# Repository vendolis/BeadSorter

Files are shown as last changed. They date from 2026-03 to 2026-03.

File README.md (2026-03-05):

# BeadSorter
The is a modified version based on the bead sorter by HEN3DRIK [BeadSorter](https://github.com/HEN3DRIK/BeadSorter)

# References
These are Projects necessary for this beadsorter to work.

Original Project by Linus Barth:
[BeadSort: Machine for sorting perler beads by LinusB - Thingiverse](https://www.thingiverse.com/thing:2598302)

Modified to skip aligner phase by RichA777
[Bead Sorter modified to skip aligner phase by RichA777 - Thingiverse](https://www.thingiverse.com/thing:4507571)

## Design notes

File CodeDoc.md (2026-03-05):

# BeadSorter

An Arduino-based automated bead sorting machine that uses a color sensor to identify beads and route them into separate containers by color.

---

## Physical Stages

The machine is divided into numbered physical stages, each with corresponding 3D-printed parts:

| Stage | Name | Description |
|---|---|---|
| 0 | Hopper | Bulk bead storage reservoir |
| 1 | Sequentializer | DC motor agitates beads into a single-file tube |
| 3 | Analyzer | Servo-controlled gate presents one bead at a time to the color sensor |
| 4 | Dispatcher | Stepper-driven rotating carousel directs the bead to the correct output |
| 5 | Outputs | Ring of output containers (up to 15 color bins + 1 overflow) |

---

## Hardware

### Components

| Component | Purpose |
|---|---|
| Arduino (Nano/Uno) | Main controller |
| TCS34725 color sensor | Reads RGBC values of each bead via I2C |
| Servo motor | Gate in the analyzer stage — swings in/out to present a bead to the sensor |
| Stepper motor (200 steps/rev) | Rotates the output carousel to the correct container |
| L298N / H-bridge | Drives the DC hopper motor |
| DC motor (hopper) | Agitates beads from the hopper into the sequentializer tube |
| Photoresistor / LDR | Detects whether beads are present in the feeding tube |
| Push button | Setup / calibration trigger |

### Pin Assignments

| Pin | Name | Function |
|-----|---|---|
| D2 | `dirPin` | Stepper direction |
| D3 | `stepPin` | Stepper step pulse |
| D5 | `GSM2` | Hopper motor PWM speed |
| D6 | `in4` | Hopper motor direction B |
| D7 | `in3` | Hopper motor direction A |
| D8 | `servoPin` | Servo PWM |
| D11 | `setupPin` | Setup/calibration button (INPUT) |
| A0 | `photoSensorPin` | Photoresistor (analog) |
| SDA/SCL | I2C | TCS34725 color sensor |

---

## Software Architecture

### Libraries Required

- `Servo.h` — Arduino servo control
- `AccelStepper.h` — Stepper motor with acceleration/deceleration
- `Wire.h` — I2C communication
- `Adafruit_TCS34725.h` — TCS34725 color sensor driver

### Main Loop Flow

```
loop()
  │
  ├─ Handle serial commands (e.g. 't' to print tables)
  │
  ├─ handleHopperMotor()        ← keep beads flowing; reverse if stuck
  │
  ├─ Check setup button         ← if pressed: enter manual color registration
  │
  ├─ servoFeedIn()              ← swing servo to "in" position, presenting bead
  │
  ├─ readColorSensor()          ← read RGBC from TCS34725
  │
  ├─ nullScan()?
  │    ├─ YES (no bead) → print ".", servoFeedOut(), loop
  │    └─ NO  (bead detected)
  │         ├─ sortBeadToDynamicArray()
  │         │    ├─ findColorInStorage()   ← up to 4 retries with wiggle
  │         │    ├─ getContainerNo()       ← map color index → carousel slot
  │         │    └─ moveSorterToPosition() ← rotate stepper to that slot
  │         └─ servoFeedOut()             ← release bead into carousel
```

### Startup Sequence

1. Initialise all pins and peripherals.
2. If `calibrateNullScan = true`: wiggle the servo 6 times (to settle), then read the empty-sensor baseline and store it as the null-scan reference.
3. If `autoSort = false`: load the 13 preset default colors.
4. Begin the main loop.

---

## Operating Modes

### Auto-Sort Mode (`autoSort = true`, default)

The machine learns colors on the fly:
- Every new color that doesn't match anything stored is automatically assigned to the next free container slot.
- Up to **15 distinct colors** can be learned and sorted.
- When all 15 slots are full, unrecognised beads go to the last container (slot 15 = overflow).
- Thresholds: `thresholdFactor = 0.04`, `offset = 40`.

### Manual / Preset Mode (`autoSort = false`)

Activated by pressing the setup button during runtime (or set at compile time):
- Uses 13 hardcoded reference colors (Orange, Yellow, Green, Dark Blue, Rose, Skin, Red, White, Black, Lime Green, Mint Green, Coral, Dark Yellow).
- Tighter matching thresholds: `thresholdFactor = 0.03`, `offset = 20`.
- New colors can still be registered manually — press the setup button, load a single color type into the hopper, then press again to scan 4 samples and compute a mean reference.

---

## Color Matching

### Sensor Configuration

```cpp
Adafruit_TCS34725 tcs = Adafruit_TCS34725(TCS34725_INTEGRATIONTIME_101MS, TCS34725_GAIN_16X);
```

The sensor returns four 16-bit channels: **Clear (C), Red (R), Green (G), Blue (B)**.

### Null Scan (Empty-Sensor Detection)

On startup the empty-sensor RGBC values are recorded as `nullScanValues[]`. Each loop iteration, if the measured RGBC is within ±`nullScanOffset` (150) of these baseline values on all four channels, `nullScan()` returns `true` — meaning no bead is present.

### Color Identification (`findColorInStorage`)

Each stored color is compared channel by channel. For each channel the allowed window is:

```
threshold = thresholdFactor × measured_value + offset
window    = [measured − threshold, measured + threshold]
```

A stored color matches only if **all four channels** fall within their respective windows. The first match found wins.

### Retry Logic

If no match is found immediately, the servo wiggles the bead (`servoWiggleIn`) and re-reads up to **4 times**. The four readings are averaged (mean) before a final unmatched bead is stored as a new auto-color.

### Color Distance (Euclidean)

`colorDistance()` computes the 4D Euclidean distance between two RGBC vectors. This is logged to Serial for debugging but is not used in the primary matching logic (which uses the per-channel threshold approach above).

---

## Stepper / Carousel

| Parameter | Value |
|---|---|
| Steps per revolution | 200 |
| Microstepping | 16× |
| Container slots defined | 16 (12 physically used) |
| Steps per slot | `200 × 16 / 16 = 200` |
| Max speed | 6000 steps/s |
| Acceleration | 9000 steps/s² |

`moveSorterToPosition()` always takes the **shortest path** — if the forward distance is more than 8 slots it wraps around in reverse, and vice versa. After moving, the absolute position is normalised back into the 0–15 slot range to prevent integer overflow over long runs.

### Container Array

`dynamicContainerArray[16]` maps color indices to physical carousel slots. Pre-seeded with sentinel value `666` at slots 1, 5, 9, 13 (reserved/dividers) and `-1` (free) elsewhere. Slot 15 is the overflow bin.

---

## Hopper Motor Control

The DC hopper motor runs continuously while the photosensor reports no beads in the tube (sensor value > `photoSensorThreshold` = 600).

If no bead has been successfully sorted for more than `hopperMotorReverseTime` (9 s), the motor **reverses direction** to dislodge jams. The direction resets on each successful bead.

---

## Servo Positions

| Position | Angle | Description |
|---|---|---|
| In | 28° ± 2° | Bead held under sensor |
| Out | 51° ± 2° | Bead released to carousel |
| Wiggle | ±4° around `In` | Repositions bead for re-reading |

`servoFeedOut()` cycles the "out" wiggle **3 times** to ensure the bead is fully ejected.

---

## Serial Interface

Baud rate: **9600**

| Input | Action |
|---|---|
| `t` or `T` | Print null-scan values, all stored colors, and the container array |

### Output Format

- `.` — no bead detected (null scan)
- `Photosensor detected Beads <value>` — tube is full, hopper stopped
- `Beads analyzed: N` followed by RGBC values — bead detected
- `Color is #<name>` — matched color (manual mode) or RGBC (auto mode)
- `Color Distance is: <d>` — Euclidean distance to matched reference
- `move stepper to container No: <n>` — target slot
- `not found` + `autosort!` — new color being learned

---

## Configuration Reference

All key parameters are `#define` constants at the top of [BeadSorter.ino](BeadSorter.ino):

| Constant | Default | Description |
|---|---|---|
| `stepperMaxSpeed` | 6000 | Stepper max steps/s |
| `stepperAccel` | 9000 | Stepper acceleration steps/s² |
| `stepperStepsPerRot` | 200 | Motor steps per revolution |
| `stepperMicroStepping` | 16 | Driver microstepping factor |
| `numContainerSlots` | 16 | Logical slot count |
| `motorSpeed` | 255 | Hopper motor PWM (0–255) |
| `hopperMotorReverseTime` | 9000 | ms before reversing hopper on jam |
| `photoSensorThreshold` | 600 | ADC level above which tube is empty |
| `nullScanOffset` | 150 | ±tolerance for empty-sensor detection |
| `servoAngleIn` | 28° | Servo scan position |
| `servoAngleOut` | 51° | Servo release position |
| `servoAngleWiggle` | 2° | Servo dither amplitude |
| `thresholdFactor` | 0.04 | Color match window scaling factor |
| `offset` | 40 | Color match minimum window (counts) |
| `calibrateNullScan` | true | Auto-calibrate empty sensor on boot |
| `autoSort` | true | Learn colors automatically |

---

## Debug Modes

Uncomment a `DEBUG_PROG` define to enable a debug loop at startup:

| Value | Mode |
|---|---|
| `1` | Stepper test: repeatedly moves to position 1000 and back |
| `2` | Color sensor test: prints live RGBC readings every 400 ms |

`DEBUG_PRINT_PHOTOSENS` — if defined, prints the raw photosensor ADC value every loop iteration.

---

## Known Issues / Notes

- `calcMedianAndStore()` computes a **mean**, not a median (acknowledged in a comment).
- The `updateDetectedColorFromTempStoredColor` / `updateStoredColorCount` running-average update feature is commented out.

### VS Code IntelliSense warning

IntelliSense may report *"PCH warning: header stop cannot be in a linkage block"* on the last `#include` line. This is **not a real compiler error** — it is caused by `Arduino.h` using `extern "C"` blocks internally which confuse the MSVC-style PCH engine. It is suppressed by setting `"intelliSenseMode": "gcc-x86"` in [.vscode/c_cpp_properties.json](.vscode/c_cpp_properties.json), which matches the actual AVR-GCC toolchain.

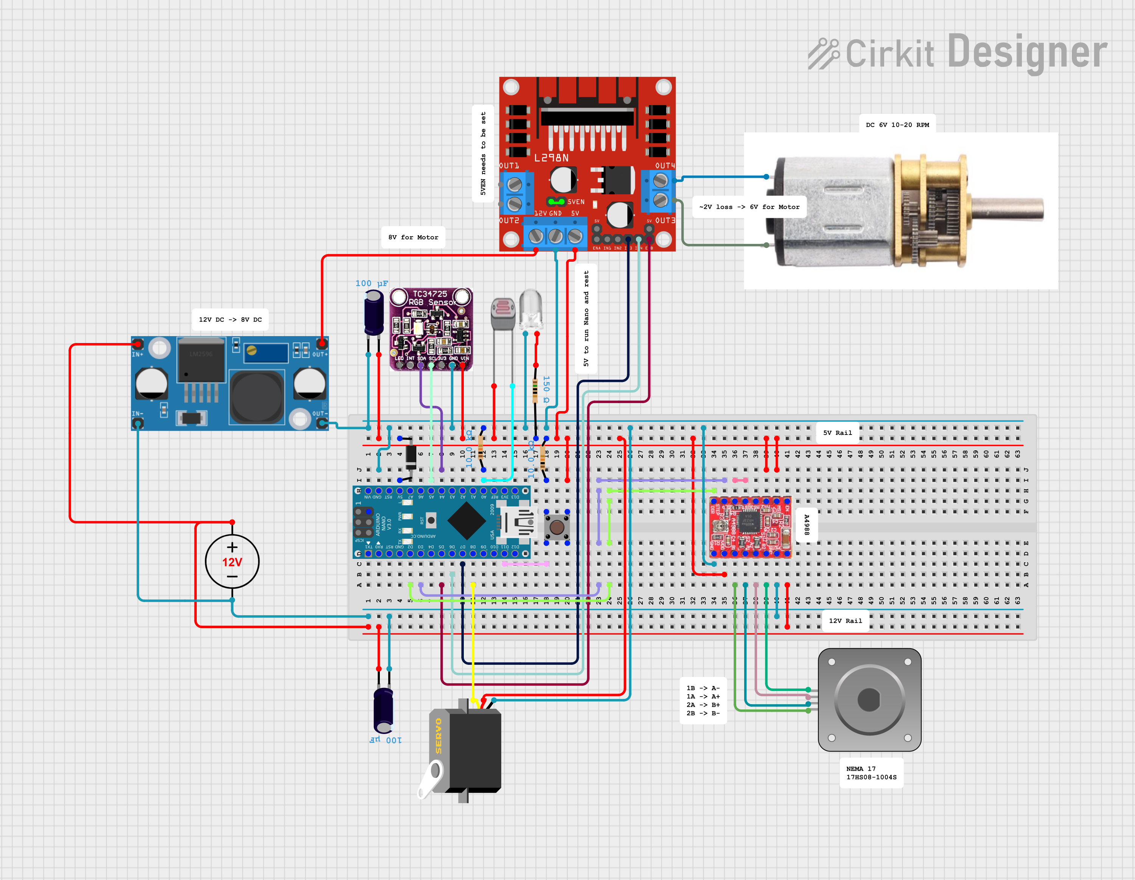
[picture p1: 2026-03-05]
beadsorter_schema_revised_v1.png

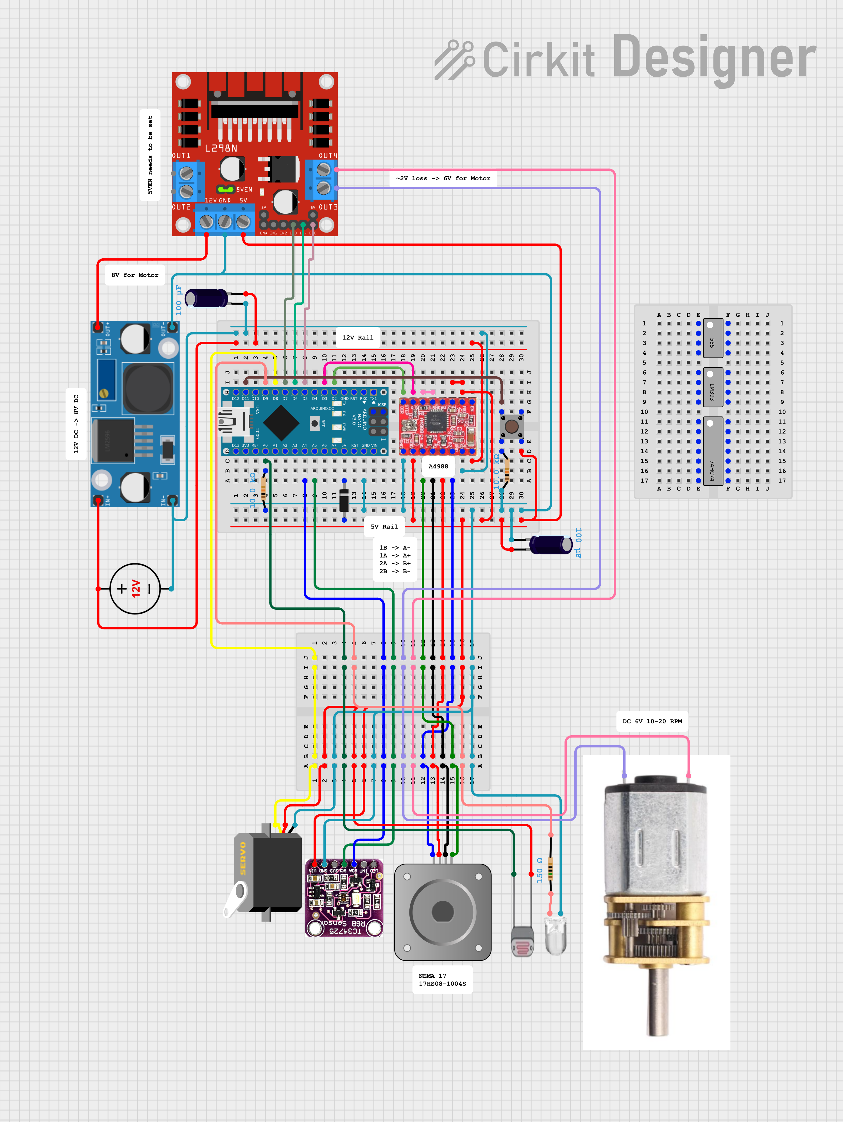
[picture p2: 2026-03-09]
beadsorter_schema_revised_v2.png

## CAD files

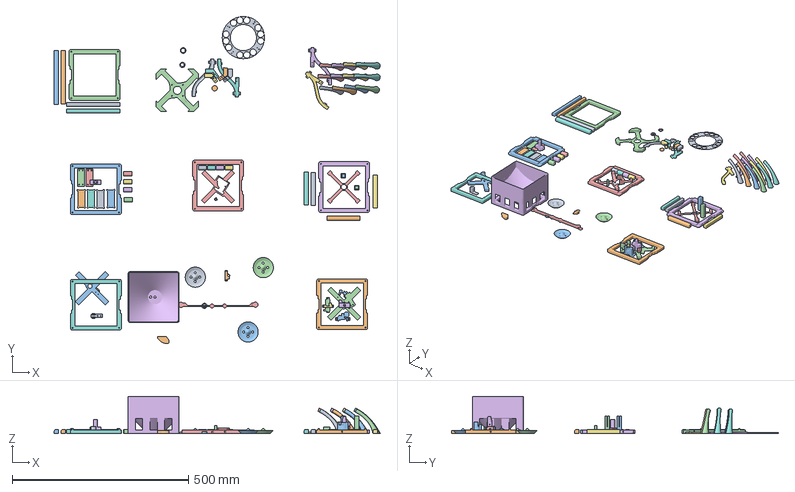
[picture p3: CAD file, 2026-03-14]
Beadsorter.3mf
925.0 x 926.4 x 105.0 mm
0-hopper-seq-plate-4_holes_modified.stl
0-hopper-seq-stopper.stl
1-sequentializer-ilc-bottom.stl
1-sequentializer-ilc-corner_for_higher_motor.stl
1-sequentializer-ilc-top.stl
1-sequentializer-motor-holder.stl
3-analyzer-entry-tube_modified.stl
3-analyzer-exit-base_V7.stl
3-analyzer-exit-tube.stl
3-analyzer-ilc-bottom.stl
3-analyzer-ilc-corner.stl
3-analyzer-ilc-top.stl
3-analyzer-separation-arm_v8.stl
3-analyzer-servo-holder.stl
3-analyzer-top-alignment.stl
4-dispatcher-ilc-bottom.stl
4-dispatcher-ilc-corner.stl
4_Stepper_shaft.stl
4_Stepper_shaft_alternative_3mm_square-Körper.stl
4-dispatcher-tube-alignment.stl
4-dispatcher-tubehalf-1.stl
4-dispatcher-tubehalf-2.stl
5-outputs-ilc-corner.stl
5-outputs-ilc-top.stl
5-outputs-slide-1.stl
5-outputs-slide-2.stl
5-outputs-slide-3.stl
Plate.stl
ring_container.stl
2_Sequencer_base_modified_v2.stl
Servo_base2.stl
Stepper_shaft_ring.stl
0-Hopper_Modified_Cleaned_up.stl
holder_typeA.stl
holder_Typeb.stl
hopper-seq-plate-4_holes_modified_Glides.stl x 2
HopperStick Holder v2.stl
2_Sequencer_tube_modified_v11.stl
2_Sequencer_tube_modified_Ring_WithCenter.stl
SectionBracketPegs.stl
SectionBracketHoles.stl
2_Sequencer_tube_modified_v2.stl
3-analyzer-entry-tube_modified_v7.stl
4-dispatcher-tubehalf-1_modified.stl
4-dispatcher-tubehalf-2_modified.stl
Shape-Cylinder
4-dispatcher-tube-ring_v3.stl
3-analyzer-base_v2.stl_4
3-analyzer-exit-base_testRigs_v2.stl_1
3-analyzer-exit-base_testRigs_v2.stl_1_2

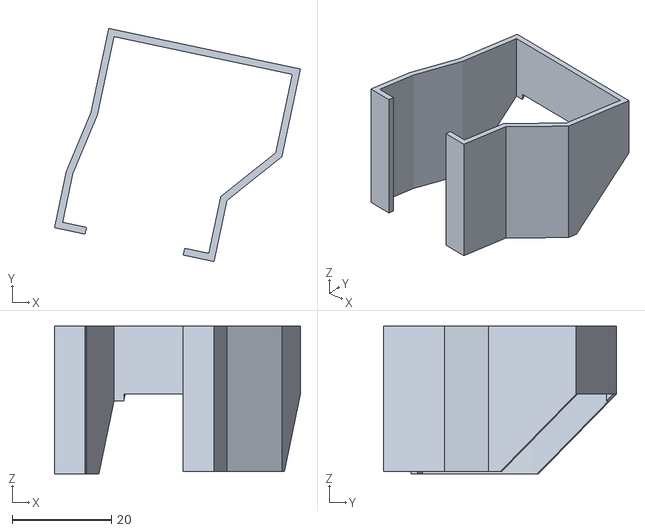
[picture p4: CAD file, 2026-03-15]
STLs/3-analyzer-shroud.stl
49.6 x 47.0 x 29.8

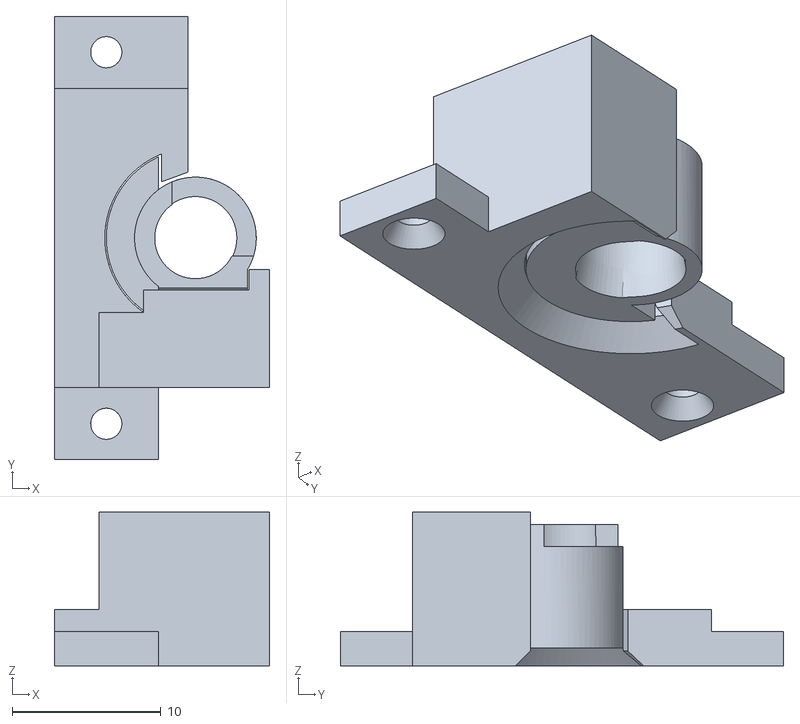
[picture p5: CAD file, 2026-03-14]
STLs/3-analyzer-entry-tube_modified_v8.stl
14.5 x 29.8 x 10.4

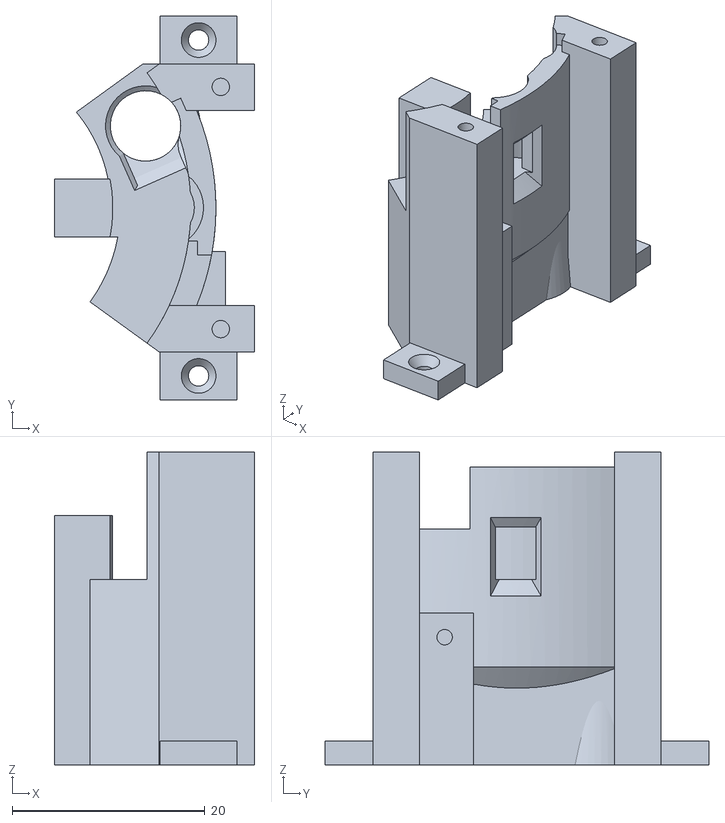
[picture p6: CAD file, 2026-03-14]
STLs/3-analyzer-exit-base_v13.stl
20.8 x 39.8 x 32.5

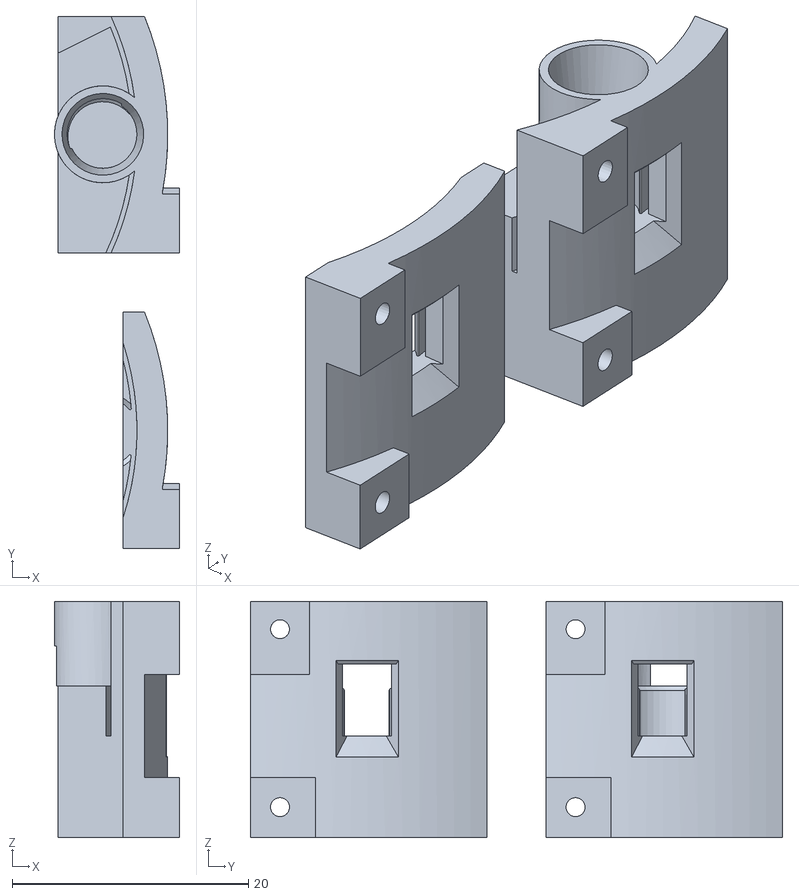
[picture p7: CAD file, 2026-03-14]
STLs/3-analyzer-exit-base_testRigs_v2.stl
10.6 x 45.0 x 20.0

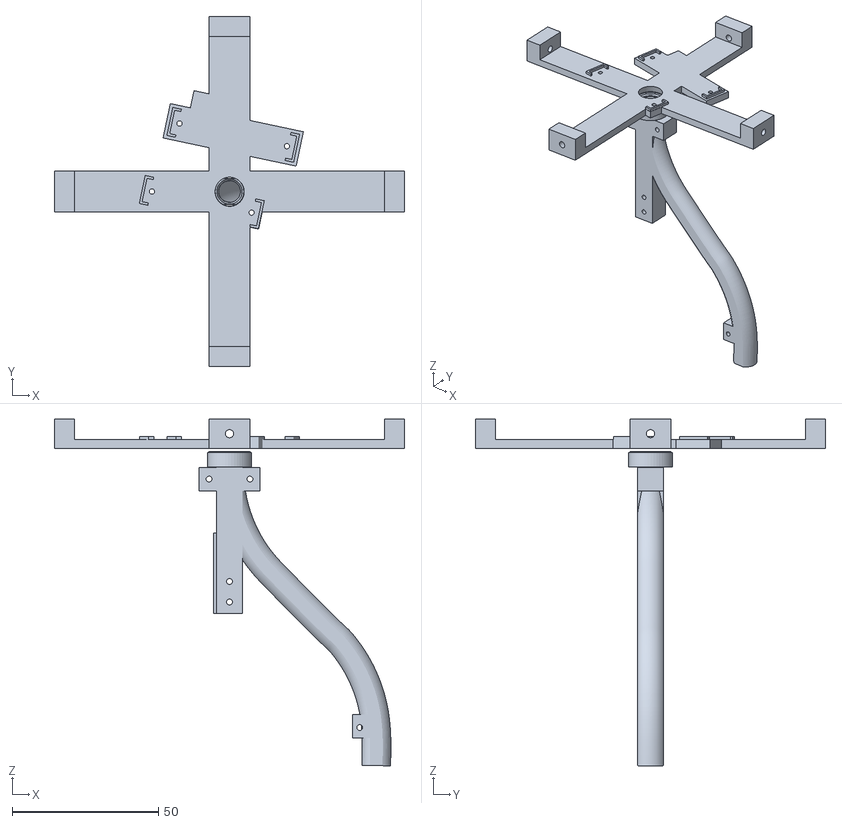
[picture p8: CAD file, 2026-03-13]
STLs/3-analyzer-base_v2.stl
119.6 x 119.6 x 118.5

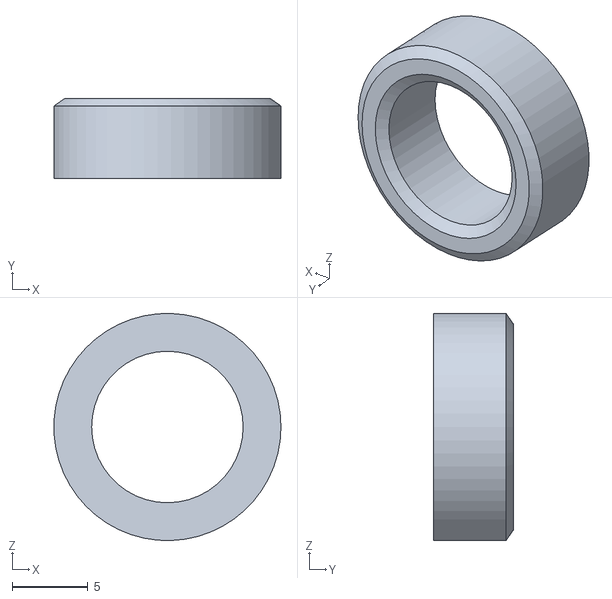
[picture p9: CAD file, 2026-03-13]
STLs/4-dispatcher-tube-ring_v3.stl
15.0 x 5.30 x 15.0

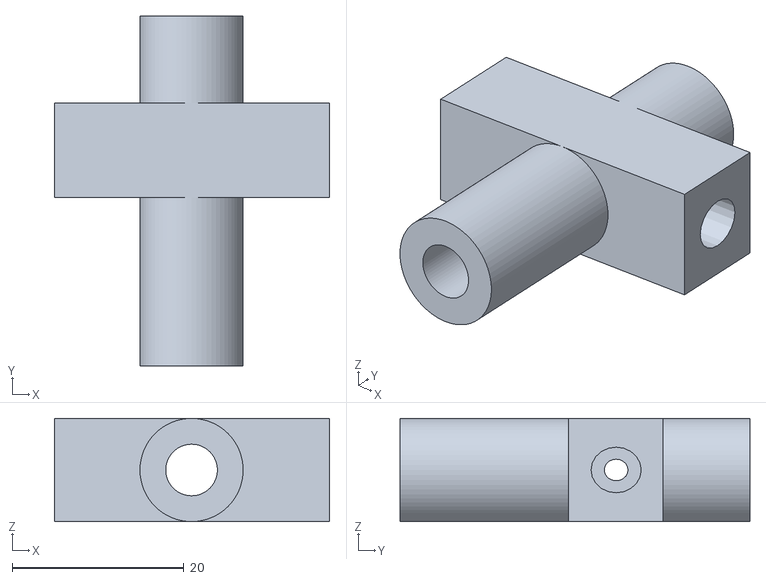
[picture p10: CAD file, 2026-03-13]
STLs/2_Sequencer_tube_modified_tighter_Higher_Motor.stl
32.0 x 40.7 x 12.0

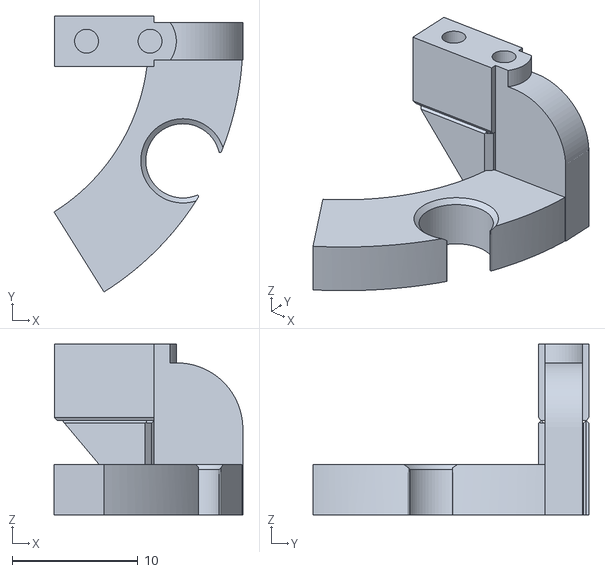
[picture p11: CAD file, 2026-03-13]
STLs/3-analyzer-separation-arm_v8.stl
15.0 x 21.9 x 13.6

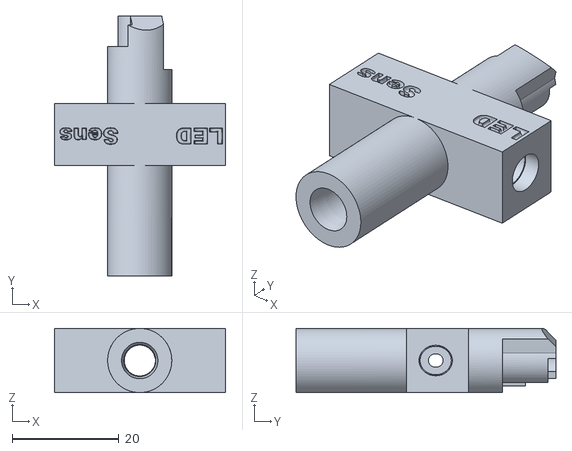
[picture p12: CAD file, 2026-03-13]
STLs/2_Sequencer_tube_modified_v11.stl
32.0 x 48.6 x 12.0

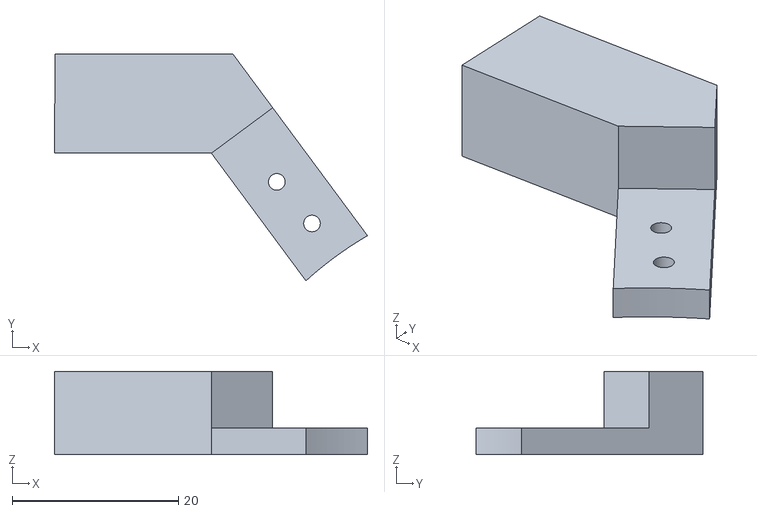
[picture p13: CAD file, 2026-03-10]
STLs/5-outputs-slidePlate-holder_typeA.stl
37.6 x 27.3 x 10.0

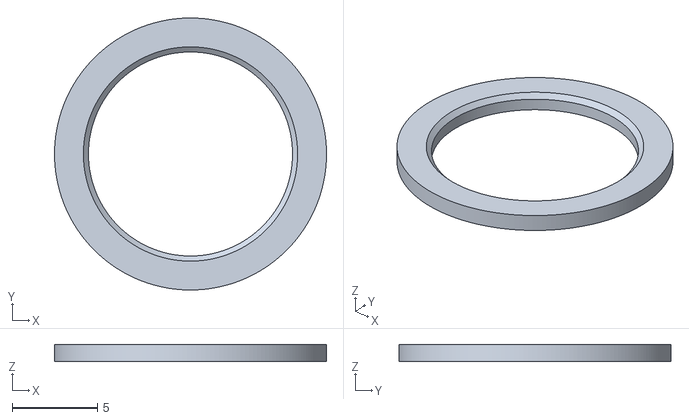
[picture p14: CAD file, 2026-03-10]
STLs/0_Hopper_container_ring.stl
16.0 x 16.0 x 1.00

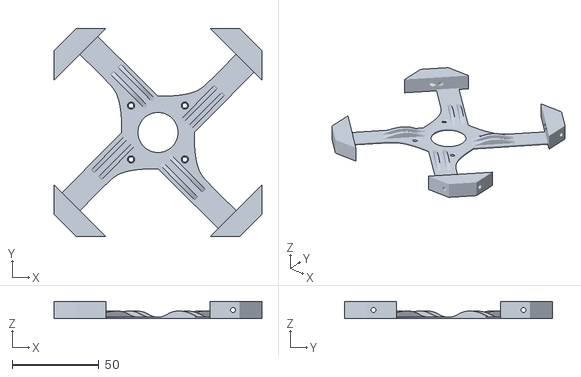
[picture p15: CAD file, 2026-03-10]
STLs/4-dispatcher-Stepper_base2.stl
119.8 x 119.8 x 10.0

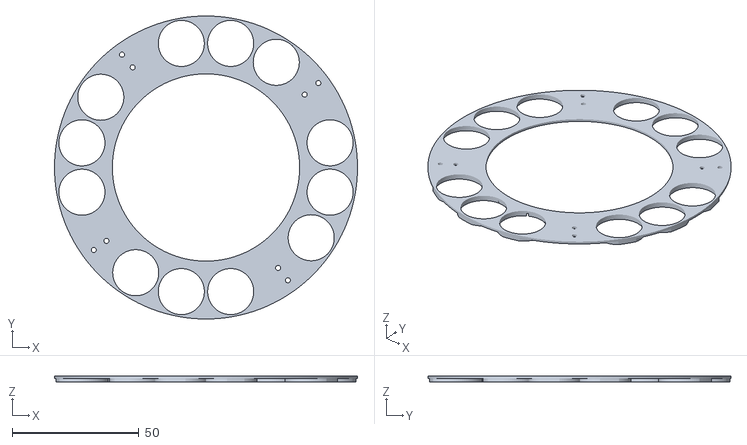
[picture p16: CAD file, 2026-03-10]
STLs/5-Outputs-SlidePlate.stl
119.7 x 119.7 x 2.50

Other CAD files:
STLs/3-analyzer-exit-base_testBlocks.stl
STLs/2_Sequencer_base_modified_v2.stl
STLs/4-dispatcher-Tube-alignment-ring.stl
STLs/4-dispatcher-Stepper-shaft.stl
STLs/0-Hopper_Modified_Cleaned_up.stl
STLs/0-hopper-seq-plate-4_holes_modified.stl
STLs/0-hopper-seq-stopper.stl
STLs/0_HopperStick Holder v2.stl
STLs/1-sequentializer-ilc-bottom.stl
STLs/1-sequentializer-ilc-top.stl
STLs/1-sequentializer-motor-holder.stl
STLs/2_Sequencer_base_modified.stl
STLs/2_Sequencer_tube_modified_v10.stl
STLs/2_Sequencer_tube_modified_v2.stl
STLs/2_Sequencer_tube_modified_v4_AntiStall.stl
STLs/3-analyzer-base.stl
STLs/3-analyzer-entry-tube_Extended.stl
STLs/3-analyzer-entry-tube_modified_v4.stl
STLs/3-analyzer-entry-tube_modified_v7.stl
STLs/3-analyzer-exit-base.stl
STLs/3-analyzer-exit-base_V7.stl
STLs/3-analyzer-exit-base_v12.stl
STLs/3-analyzer-exit-base_v3.stl
STLs/3-analyzer-exit-base_v8.stl
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

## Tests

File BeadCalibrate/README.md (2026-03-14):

# BeadSorter Colour Calibration Toolchain

Two files work together to find the best colour-space and sensor settings for
your bead set before tuning `BeadSorter.ino`.

| File | What it does |
|---|---|
| `BeadCalibrate/BeadCalibrate.ino` | Runs the full machine, collects colour data for each bead, outputs CSV |
| `analyse_beads.py` | Reads that CSV, compares colour spaces and gains, suggests thresholds |

---

## Hardware

Identical wiring to `BeadSorter.ino` — no changes needed.
The stepper carousel is **not moved** during calibration; all beads fall into
whichever slot is currently positioned under the chute.

---

## BeadCalibrate.ino

### What it does

For every bead that passes through the sensor:

1. Feeds the bead in with the servo (`servoFeedIn`).
2. Checks whether a bead is actually present (null scan at 16× gain).
3. If a bead is detected, takes **NUM\_READINGS wiggle positions**.
   At each position it reads all **4 gain settings** (1×, 4×, 16×, 60×)
   before moving to the next wiggle — so each bead produces
   `NUM_READINGS × 4` CSV rows.
4. Releases the bead (`servoFeedOut`) and waits for the next one.

### Setup

1. Flash `BeadCalibrate.ino` to the Arduino.
2. Open Serial Monitor at **115200 baud** (BeadSorter.ino uses 9600 — change
   the setting in your IDE).
3. Let the machine run. Beads are fed automatically by the hopper.
4. When all beads have been processed, copy the full Serial output and save it
   as a `.csv` file (e.g. `beads.csv`).

> **Tip:** Lines starting with `#` are comments — the header line, bead
> markers, rejected-bead diagnostics. `analyse_beads.py` skips them
> automatically.

### Configuration

All tuning constants are at the top of the sketch under
`// ── Calibration parameters ──`:

| Constant | Default | Description |
|---|---|---|
| `NUM_READINGS` | `10` | Wiggle positions per bead |
| `CALIB_INTTIME` | `TCS34725_INTEGRATIONTIME_101MS` | Integration time for every gain step |
| `GAIN_SETTLE_MS` | `220` | ms to wait after `setGain()` before reading (must be > integration period) |
| `NULL_SCAN_GAIN_IDX` | `2` (= 16×) | Which entry in `GAINS[]` is used for the null-scan check |
| `SAT_THRESH` | `60000` | Raw count above which a channel is flagged as saturated |
| `NULL_OFFSET_H/S/L` | `0.03 / 0.05 / 0.05` | How close a reading must be to the empty-tube reference to be rejected |

The gain sweep table is:

```cpp
{ TCS34725_GAIN_1X,  "g1x"  },
{ TCS34725_GAIN_4X,  "g4x"  },
{ TCS34725_GAIN_16X, "g16x" },   // ← also used for null scan
{ TCS34725_GAIN_60X, "g60x" },
```

### Null scan

At startup the servo cycles 6 times with an empty tube and records the baseline
HSL reading at 16×. During the main loop, each bead is checked against this
baseline before the gain sweep starts. A reading is **rejected** (no bead)
only when all three channels are within their `NULL_OFFSET` of the baseline
simultaneously (AND logic).

Rejected beads print a diagnostic line:

```
# REJECTED  read: H=0.1300 S=0.2280 L=0.3190  null ref: H=0.1316 S=0.2317 L=0.3216
```

If legitimate beads are being rejected, reduce `NULL_OFFSET_H/S/L` further.
If empty-tube readings are being accepted as beads, increase them.

### CSV output format

```
bead,gain,sample,R_raw,G_raw,B_raw,C_raw,saturated,R_norm,G_norm,B_norm,chroma_r,chroma_g,chroma_b,H,S,L
```

| Column | Range | Description |
|---|---|---|
| `bead` | 1 … N | Sequential bead number |
| `gain` | g1x / g4x / g16x / g60x | Gain setting for this row |
| `sample` | 1 … NUM\_READINGS | Wiggle position index |
| `R_raw` … `C_raw` | 0 … 65535 | Raw 16-bit RGBC counts from sensor |
| `saturated` | 0 / 1 | 1 if any channel ≥ SAT\_THRESH |
| `R_norm` … `B_norm` | 0 … 255 | Clear-channel-normalised float RGB (from `getRGB()`) |
| `chroma_r` … `chroma_b` | 0 … 1 | R/(R+G+B) etc. — ambient-independent colour signature |
| `H`, `S`, `L` | 0 … 1 | HSL derived from normalised RGB; H is circular (0 = red) |

---

## analyse_beads.py

### Requirements

Python 3.6+, standard library only (no pip installs needed).

### Usage

```bash
# Analyse a single collection run:
python analyse_beads.py beads.csv

# Restrict to one gain only:
python analyse_beads.py beads.csv --gain g16x

# Show more closest-pair rows:
python analyse_beads.py beads.csv --top 20
```

### What it reports

#### 1 — Saturation summary

How many rows per gain setting had a saturated channel.
A high saturation percentage at 60× means that gain clips signal and loses
colour information — prefer a lower gain for those beads.

#### 2 — Per-bead mean values

For each gain setting, a table of mean H, S, L, chroma\_r, chroma\_g, chroma\_b
per bead (saturated rows excluded).  Also reports average intra-bead noise
(standard deviation) per channel — lower is more stable.

#### 3 — Colour-space separability

For each gain × colour-space combination, the **minimum pairwise distance**
between any two beads is computed.  A higher minimum means the beads are
easier to separate.

| Space | What it measures |
|---|---|
| `HSL` | Euclidean distance with circular hue |
| `HS` | Same but ignoring L — tests whether lightness helps |
| `Chroma2` | 2-D chromaticity (chroma\_r, chroma\_g) |
| `Chroma3` | 3-D chromaticity (all three fractions) |
| `NormRGB` | Euclidean distance in normalised RGB (0–255 scale) |

The space with the highest minimum pairwise distance is the best discriminator
for your specific bead set.

#### 4 — Closest pairs

The N hardest-to-separate bead pairs in the best colour space, sorted by
distance.  Pairs flagged `← may collide` have a distance below 0.040 and
may be misclassified by `BeadSorter.ino` depending on threshold settings.

#### 5 — Threshold suggestions

Half the minimum per-channel inter-bead gap — the tightest threshold that
does not split any bead pair in that channel.  Reported for both HSL and
Chroma2:

```
Suggested thresholds for BeadSorter.ino (half the min inter-bead gap):
  HSL:       thresholdH = 0.0182  thresholdS = 0.0310  thresholdL = 0.0120
  Chroma2:   threshold  = 0.0240  (Euclidean distance in chroma_r / chroma_g plane)
```

#### 6 — Cross-gain comparison

A summary table showing separability scores across all gains and colour spaces,
followed by the recommended gain and colour space combination.

### Interpreting the results

| Finding | What to do |
|---|---|
| High saturation % at g60x | Don't use 60× in BeadSorter.ino for these beads |
| `Chroma2` score > `HSL` score | Consider switching BeadSorter.ino to store chroma\_r / chroma\_g instead of H/S/L |
| High intra-bead `std_H` | Hue is noisy for those beads (low saturation); rely more on S or chromaticity |
| Two beads always close in every space | They may physically be the same colour; no threshold can separate them |
| Suggested thresholdH is very small (< 0.010) | Hue alone won't separate all beads; the AND-logic of H+S+L helps |

### Applying the results to BeadSorter.ino

Update the threshold constants near the top of `BeadSorter.ino`:

```cpp
float thresholdH = 0.020;   // ← replace with suggested value
float thresholdS = 0.040;   // ← replace with suggested value
float thresholdL = 0.040;   // ← replace with suggested value
```

If the recommended gain differs from the current 16×, update the sensor
initialisation line:

```cpp
// Example: switch to 4×
Adafruit_TCS34725 tcs = Adafruit_TCS34725(TCS34725_INTEGRATIONTIME_101MS,
                                           TCS34725_GAIN_4X);
```

---

## Swatch image generators

Three helper scripts produce visual colour-swatch sheets from calibration data.
They are independent of each other — use whichever matches your run.

### gen_swatches.py — simple accepted-bead sheet

Reads a **clean CSV** (saturated rows already removed, or use the raw CSV and
let it filter by `saturated == 0`).  Shows only accepted beads; no null
reference, no rejects.  Useful as a quick sanity-check after a first
calibration run.

```bash
# Edit the two constants at the top of the file before running:
#   CSV_FILE = "beads_clean.csv"   ← your clean CSV path
#   GAIN     = "g4x"               ← which gain to visualise
python gen_swatches.py
# Writes: bead_swatches_g4x.png
```

**Requires:** Pillow (`pip install pillow`).
**Input:** clean CSV only.

---

### gen_swatches_white.py — white-background run with clustered rejects

Produces a three-section sheet:

1. **Null reference** — the empty-tube baseline swatch.
2. **Accepted beads** — mean NormRGB colour + ΔH/ΔS/ΔL vs null ref.
3. **Rejected bead clusters** — groups of near-identical rejections
   (within 0.02 H / 0.03 S / 0.04 L of each other are merged into one
   cluster swatch).  A red border flags clusters whose mean HSL sits
   within the null-scan tolerances (0.03/0.05/0.05) of the null
   reference — those are "too close to empty tube" rejections.

```bash
# Edit at the top of the file:
#   CSV_RAW   = "BeadCalibration_20260313_whitebackground.csv"  ← raw serial output
#   CSV_CLEAN = "beads_white_clean.csv"                         ← clean CSV
#   GAIN      = "g16x"
python gen_swatches_white.py
# Writes: bead_swatches_white_bg.png
```

**Requires:** Pillow.
**Inputs:** raw serial-output CSV **and** clean CSV.  The raw file is parsed
for `# Null ref:` and `# REJECTED … read: … null ref: …` comment lines
emitted by `BeadCalibrate.ino`.

Use this variant when you want to understand **recurring reject patterns**
(e.g. a single bead colour that consistently fails the null scan).

---

### gen_swatches_largewin.py — individual-reject diagnostic sheet

Identical three-section layout to `gen_swatches_white.py`, but the third
section shows **every individual rejection** as its own swatch rather than
grouping them.  The `NULL_OFF` constant `(0.03, 0.05, 0.05)` matches
`NULL_OFFSET_H/S/L` in `BeadCalibrate.ino` exactly; swatches whose ΔH/ΔS/ΔL
all fall within those offsets get a red border.

```bash
# Pass the raw serial-output CSV directly; no separate clean CSV needed:
python gen_swatches_largewin.py BeadCalibration_20260313_largerWindow.csv
# Writes: bead_swatches_largewin.png

# Custom output name:
python gen_swatches_largewin.py BeadCalibration_20260313_improved.csv my_swatches.png

# Different gain:
python gen_swatches_largewin.py BeadCalibration_20260313_improved.csv my_swatches.png --gain g4x
```

**Requires:** Pillow.
**Input:** raw serial-output CSV only (serves as both data source and comment parser).

Use this variant when you want to inspect **each individual rejection event**
(e.g. to see whether a bead is consistently rejected or only occasionally,
and what its exact HSL values were each time).

---

### Which script to use?

| Situation | Script |
|---|---|
| First look at colours from a new run | `gen_swatches.py` |
| Many beads are failing the null scan; identify the recurring pattern | `gen_swatches_white.py` |
| Debug specific rejection events one by one | `gen_swatches_largewin.py` |

### Dependency on BeadCalibrate.ino comment format

`gen_swatches_white.py` and `gen_swatches_largewin.py` parse the raw
serial-output file using regular expressions that match two specific comment
formats emitted by `BeadCalibrate.ino`:

```
# Null ref: H=0.1316  S=0.2317  L=0.3216
# REJECTED 3  read: H=0.1300 S=0.2280 L=0.3190  null ref: H=0.1316 S=0.2317 L=0.3216
```

If you modify the `Serial.print` statements in `BeadCalibrate.ino` that
produce these lines, you must update the regex patterns in both scripts
accordingly.

---

## Full workflow

```
1. Flash BeadCalibrate.ino
2. Open Serial Monitor at 115200 baud
3. Run all beads through the machine
4. Copy Serial output → save as beads.csv  (this is the "raw" file)
5. python analyse_beads.py beads.csv
6. Note recommended gain and thresholds
7. (Optional) Run a swatch script to visualise colours:
     python gen_swatches.py            # quick look, accepted beads only
     python gen_swatches_white.py      # clustered rejects + null ref
     python gen_swatches_largewin.py   # individual rejects + null ref
8. Update BeadSorter.ino with new gain and threshold values
9. Re-flash BeadSorter.ino and verify sorting accuracy
```

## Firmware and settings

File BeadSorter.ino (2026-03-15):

#include <Arduino.h>
#include <Servo.h>
#include <AccelStepper.h>
#include <Wire.h>
#include <Adafruit_TCS34725.h>
#include "ColorConverterLib.h"

// Stubs so VS Code IntelliSense resolves AVR-specific macros.
// These lines are never compiled by the Arduino toolchain.
#ifdef __INTELLISENSE__
  #define F(x) x
  #define PSTR(x) x
  #define snprintf_P snprintf
  typedef char __FlashStringHelper;  // makes const __FlashStringHelper* == const char*
  // Under IntelliSense 'SafeSerial' is just Serial so all Print overloads resolve.
  //#define SafeSerial Serial
#else
  /*
   * SafePrint — non-blocking serial wrapper.
   * Inherits every print() / println() overload from the Arduino Print base class.
   * The TX-buffer check is done once inside write(), not at every call site,
   * keeping flash usage minimal. Output is silently dropped when the buffer
   * has fewer than 2 bytes free, preventing spin-wait hangs with no terminal.
   */
  /*class SafePrint : public Print {
  public:
    size_t write(uint8_t b) override {
      if (Serial.availableForWrite() < 2) return 0;
      return Serial.write(b);
    }
    size_t write(const uint8_t* buf, size_t n) override {
      size_t avail = (size_t)Serial.availableForWrite();
      if (avail < 2) return 0;
      if (n > avail) n = avail;
      return Serial.write(buf, n);
    }
  } SafeSerial;*/
#endif

#define dirPin 2 //Stepper
#define stepPin 3 //Stepper
#define motorInterfaceType 1 //Stepper

#define stepperMaxSpeed 6000
#define stepperAccel 9000

//#define stepperMulti 100 //Stepper
#define stepperStepsPerRot 200
#define stepperMicroStepping 8
#define numContainerSlots 16    // in reality there are only 12, but
#define stepperMulti (stepperStepsPerRot*stepperMicroStepping/numContainerSlots)

#define motorSpeed 255 //Container Motor
#define GSM2 5 // Container Motor
#define in3 7 //Container Motor
#define in4 6 //Container Motor
#define hopperMotorReverseTime  6000 //in ms - time of ~ revolution

#define setupPin 11 //Setup

#define photoLEDPin 9 //Photo Sensor LED
#define photoSensorPin A0 //Photo Sensor
#define photoSensorThreshold 600
#define photoSensorCalibMinDiff 100  // minimum on/off difference to consider LED functional

// Number of sortable color slots (bin 15 is reserved for unrecognised beads when full)
#define autoSortMaxColors 11

#define servoAngleIn 36 //Servo
#define servoAngleOut 62
#define servoAngleWiggle 2
#define servoPin 8

// #define DEBUG_PROG 1 // Stepper test
// #define DEBUG_PROG 2 // Color Sensor test
// #define DEBUG_PRINT_PHOTOSENS


// Sensor parameters — change SENSOR_GAIN here to switch gain for all modes.
// Valid gain values: TCS34725_GAIN_1X  TCS34725_GAIN_4X  TCS34725_GAIN_16X  TCS34725_GAIN_60X
#define SENSOR_INTEGRATION_TIME  TCS34725_INTEGRATIONTIME_101MS
#define SENSOR_GAIN              TCS34725_GAIN_16X

Adafruit_TCS34725 tcs = Adafruit_TCS34725(SENSOR_INTEGRATION_TIME, SENSOR_GAIN);

// HSL matching thresholds — independent per channel.
// All values are in the 0..1 range (the ColorConverterLib normalises H, S, L to 0..1).
// H wraps around (0 == 1 == red), so the comparison uses circular distance.
//
// Values below are based on the maximum intra-bead sample spread measured during
// calibration 
float thresholdH = 0.026;// 0.030;  // hue tolerance
float thresholdS = 0.023;// 0.025;  // saturation tolerance
float thresholdL = 0.010;// 0.014;  // lightness tolerance
uint16_t thresholdC = 300; // clear channel tolerance

// Null-scan window: maximum deviation from empty-tube reference in each channel.
float nullScanOffsetH = 0.008;
float nullScanOffsetS = 0.01;
float nullScanOffsetL = 0.008;
uint16_t nullScanOffsetC = 150;

Servo servo;
AccelStepper stepper = AccelStepper(motorInterfaceType, stepPin, dirPin);

bool autoSort = true;
float    resultHSL[3]  = {0.0, 0.0, 0.0};  // H, S, L  — all 0..1
uint16_t resultRaw[4]  = {0, 0, 0, 0};     // R, G, B, C  raw sensor counts
float    resultNorm[3] = {0.0, 0.0, 0.0};  // R_norm, G_norm, B_norm  (0-255, clear-normalised)

float medianHSL[4][3];  // 4-sample accumulation buffer

// storedColors[16][3] — H < 0 marks an empty slot
float storedColors[16][3] = {
  {-1,0,0},{-1,0,0},{-1,0,0},{-1,0,0},
  {-1,0,0},{-1,0,0},{-1,0,0},{-1,0,0},
  {-1,0,0},{-1,0,0},{-1,0,0},{-1,0,0},
  {-1,0,0},{-1,0,0},{-1,0,0},{-1,0,0}
};

bool calibrateNullScan = true;
// If calibrateNullScan=false, set these manually (H, S, L all 0..1).
float nullScanHSL[3] = {0.0, 0.0, 0.0};
uint16_t nullScanRAW[4] = {0, 0, 0, 0};

uint8_t  autoColorCounter = 0;
uint16_t beadCounter = 0;

const int dynamicContainerArraySize = 16;
// -1 means empty, 666 means blocked (there are only 12 total slots available due to the layout.)
// When starting the program, the arm should be over the middle slot of one of the three on the sides.
// The Unknown color slot (15) will then be the slot to the right of it.
int dynamicContainerArray[dynamicContainerArraySize] = { -1, -1, 666, -1, -1, -1, 666, -1, -1, -1, 666, -1, -1, -1, 666 , -1 };

void setup() {
  Serial.begin(115200);
  Serial.println();
  Serial.println(F("=== BeadSorter starting ==="));

  // Setup Hopper Motor Pins
  Serial.println(F("[INIT] Hopper motor pins..."));
  pinMode(GSM2, OUTPUT);
  pinMode(in3, OUTPUT);
  pinMode(in4, OUTPUT);

  Serial.println(F("[INIT] Setup button pin..."));
  pinMode(setupPin, INPUT);

  Serial.println(F("[INIT] Photo sensor LED pin..."));
  pinMode(photoLEDPin, OUTPUT);
  digitalWrite(photoLEDPin, HIGH); // LED on by default

  Serial.println(F("[INIT] Servo..."));
  servo.attach(servoPin);
  servo.write(servoAngleIn);

  Serial.print(F("[INIT] Stepper (maxSpeed=")); Serial.print(stepperMaxSpeed);
  Serial.print(F(", accel=")); Serial.print(stepperAccel); Serial.println(F(")..."));
  stepper.setMaxSpeed(stepperMaxSpeed);
  stepper.setAcceleration(stepperAccel);
  stepper.setCurrentPosition(0);

#if defined DEBUG_PROG && DEBUG_PROG == 1
  // Full 360 turn, then return to home
  Serial.println(F("[DEBUG] Stepper: full 360 turn..."));
  stepper.moveTo(stepperStepsPerRot * stepperMicroStepping);
  stepper.runToPosition();
  delay(500);
  stepper.moveTo(0);
  stepper.runToPosition();
  delay(500);

  // Visit each output slot once
  Serial.println(F("[DEBUG] Stepper: cycling all output slots..."));
  for (int slot = 0; slot < numContainerSlots; slot++) {
    Serial.print(F("[DEBUG] Slot ")); Serial.println(slot);
    stepper.moveTo(slot * stepperMulti);
    stepper.runToPosition();
    delay(500);
  }

  // Return to slot 0
  Serial.println(F("[DEBUG] Returning to slot 0..."));
  stepper.moveTo(0);
  stepper.runToPosition();
  Serial.println(F("[DEBUG] Stepper test complete."));
  while (1);
#endif

  calibratePhotoSensor();

  if (tcs.begin()) {
    Serial.println(F("[INIT] TCS34725 color sensor found."));
  } else {
    Serial.println(F("ERROR: TCS34725 not found, exiting!"));
    while (1); // Stop program
  }

#if defined DEBUG_PROG && DEBUG_PROG == 2
  servoFeedOut();
  while (1)
  {
    servoFeedIn();
    delay(500);
    servoWiggleIn();
    delay(200);
    readColorSensor();
    printBeadReading();
    delay(800);
    servoFeedOut();
  }
#endif

  Serial.print(F("[INIT] Mode: "));
  Serial.println(autoSort ? F("autoSort") : F("manual (preset colors)"));
  if (!autoSort) {
    Serial.println(F("[INIT] Importing default color set..."));
    importDefaultColorSet();
    Serial.println(F("[INIT] Default colors imported."));
  }

  if (calibrateNullScan) {
    Serial.println(F("[INIT] Null scan calibration: cycling servo..."));
    for (int i = 0; i < 6; i++) {
      Serial.print(F("  cycle ")); Serial.print(i + 1); Serial.println(F("/6"));
      servoFeedIn();
      servoFeedOut();
    }
    servoFeedIn();
    readColorSensor();
    setNullScanValues();
    Serial.println(F("[INIT] Null scan calibration done."));
  } else {
    Serial.println(F("[INIT] Null scan calibration skipped (using hardcoded values)."));
  }

  Serial.println(F("=== Setup complete. Starting continuous color scan. ==="));
  Serial.println();
}

void loop() {
  static bool successfullBead = false;

  while (Serial.available())
  {
    int c = Serial.read();
    switch (c)
    {
      case 't':
      case 'T': printTables(); break;
      default: break;
    }
  }

  handleHopperMotor(successfullBead);

  // Button press pauses/resumes scanning
  if (digitalRead(setupPin) == HIGH) {
    while (digitalRead(setupPin) == HIGH) {} // wait for release
    delay(50); // debounce
    stopHopperMotor();
    Serial.println(F("=== PAUSED — press button to resume ==="));
    while (digitalRead(setupPin) == LOW) {}  // wait for next press
    while (digitalRead(setupPin) == HIGH) {} // wait for release
    delay(50);
    Serial.println(F("=== RESUMED ==="));
  }

  servoFeedIn();
  delay(500);
  servoWiggleIn();
  delay(200);
  readColorSensor();

  if (!nullScan()) {
    Serial.println();
    Serial.print(F("Bead #")); Serial.println(beadCounter++);
    printBeadReading();
    sortBeadToDynamicArray();
    successfullBead = true;
  } else {
    Serial.println(F("No bead detected (null scan):"));
    printBeadReading();
    moveSorterToPosition(15);
    successfullBead = false;
  }

  servoFeedOut();
}

/*
*   print all color tables to serial for debugging.
*/
void printTables() {
  char line[48];

  Serial.println(F("Nullscan (H S L):"));
  snprintf_P(line, sizeof(line), PSTR("%2d H=%.4f S=%.4f L=%.4f"),
             0, nullScanHSL[0], nullScanHSL[1], nullScanHSL[2]);
  Serial.println(line);

  Serial.println(F("Stored colors (H S L):"));
  for (int i = 0; i < 16; i++) {
    if (storedColors[i][0] < 0) {
      snprintf_P(line, sizeof(line), PSTR("%2d (empty)"), i);
    } else {
      snprintf_P(line, sizeof(line), PSTR("%2d H=%.4f S=%.4f L=%.4f"),
                 i, storedColors[i][0], storedColors[i][1], storedColors[i][2]);
    }
    Serial.println(line);
  }

  Serial.println(F("Container array:"));
  for (int i = 0; i < dynamicContainerArraySize; i++) {
    Serial.print(dynamicContainerArray[i]);
    Serial.print(' ');
  }
  Serial.println();
}


/*
*  Calibrate photo sensor by toggling the LED 3 times.
*  Compares average readings with LED on vs off.
*  Halts with error if the difference is below photoSensorCalibMinDiff,
*  which indicates a broken LED or blocked line of sight.
*/
void calibratePhotoSensor() {
  Serial.println(F("[INIT] Calibrating photo sensor..."));
  int sumOn  = 0;
  int sumOff = 0;

  for (int i = 0; i < 3; i++) {
    digitalWrite(photoLEDPin, HIGH);
    delay(50);
    sumOn += analogRead(photoSensorPin);

    digitalWrite(photoLEDPin, LOW);
    delay(50);
    sumOff += analogRead(photoSensorPin);
  }

  int avgOn  = sumOn  / 3;
  int avgOff = sumOff / 3;

  digitalWrite(photoLEDPin, HIGH); // restore LED on for normal operation

  Serial.print(F("Photo sensor calib: LED on="));
  Serial.print(avgOn);
  Serial.print(F(", LED off="));
  Serial.print(avgOff);
  Serial.print(F(", diff="));
  Serial.println(abs(avgOn - avgOff));

  if (abs(avgOn - avgOff) < photoSensorCalibMinDiff) {
    Serial.println(F("ERROR: Photo sensor calib failed! LED broken or line of sight blocked."));
    while (1); // halt
  }

  Serial.println(F("Photo sensor calibration OK."));
}

/* Logic for the hopper motor
*
*  param successfullBead
*
*/
void handleHopperMotor(bool successfullBead)
{
  static unsigned long timestamp = 0;
  static bool direction = false;

  // reverse motor if no successful beads after timeout
  if (!successfullBead) {
    if (timediff(timestamp, millis()) > hopperMotorReverseTime) {
      direction = !direction;
      timestamp = millis();
    }
  } else {
    timestamp = millis();
  }

  int photoSensor = analogRead(photoSensorPin);
#ifdef DEBUG_PRINT_PHOTOSENS
  Serial.println();
  Serial.println(photoSensor);
#endif
  if (photoSensor > photoSensorThreshold) {   //PhotoSensor detected no beads in the feeding tube
    startHopperMotor(direction);
  } else {                                    //PhotoSensor detected beads in the feeding tube --> stop the motor
    stopHopperMotor();
    Serial.print(F("Photosensor detected Beads "));
    Serial.println(photoSensor);
  }
}

unsigned long timediff(unsigned long t1, unsigned long t2)
{
  signed long d = (signed long)t1 - (signed long)t2;
  if (d < 0) d = -d;
  return (unsigned long)d;
}


void servoFeedIn() {
  int low  = servoAngleIn - servoAngleWiggle;
  int high = servoAngleIn + servoAngleWiggle;
  for (int i = low; i < high; i++) {
    servo.write(i);
    delay(100);
  }
}

void servoWiggleIn() {
  int low  = servoAngleIn - servoAngleWiggle * 2;
  int high = servoAngleIn + servoAngleWiggle * 2;
  for (int c = 0; c < 3; c++) {
    servo.write(low);
    delay(100);
    servo.write(high);
    delay(100);
  }
  servo.write(servoAngleIn);
  delay(100);
}

void servoFeedOut() {
  int low  = servoAngleOut - servoAngleWiggle;
  int high = servoAngleOut + servoAngleWiggle;
  for (int count = 0; count < 3; count++) {
    for (int i = low; i < high; i++) {
      servo.write(i);
      delay(100);
    }
    for (int i = high; i > low; i--) {
      servo.write(i);
      delay(50);
    }
  }
  delay(200);
}

/*
 * Read the color sensor into resultRaw[], resultNorm[], and resultHSL[].
 *
 * One getRawData() call fills resultRaw[R,G,B,C] with raw 16-bit counts.
 * resultNorm[] is then computed by normalising each channel by the clear
 * channel (×255), matching what the library's getRGB() would return.
 * ColorConverter::RgbToHsl() converts to H, S, L all in [0..1].
 */
void readColorSensor() {
  delay(200);
  tcs.getRawData(&resultRaw[0], &resultRaw[1], &resultRaw[2], &resultRaw[3]);

  if (resultRaw[3] > 0) {
    resultNorm[0] = (float)resultRaw[0] * 255.0f / resultRaw[3];
    resultNorm[1] = (float)resultRaw[1] * 255.0f / resultRaw[3];
    resultNorm[2] = (float)resultRaw[2] * 255.0f / resultRaw[3];
  } else {
    resultNorm[0] = resultNorm[1] = resultNorm[2] = 0.0f;
  }

  double h, s, l;
  ColorConverter::RgbToHsl(
    (uint8_t)constrain((int)resultNorm[0], 0, 255),
    (uint8_t)constrain((int)resultNorm[1], 0, 255),
    (uint8_t)constrain((int)resultNorm[2], 0, 255),
    h, s, l);

  resultHSL[0] = (float)h;
  resultHSL[1] = (float)s;
  resultHSL[2] = (float)l;
}

/*
 * Print all sensor values for the current reading to Serial.
 * Format mirrors the BeadCalibrate CSV columns so readings can be
 * cross-checked directly against calibration data.
 */
void printBeadReading() {
  float rSum = resultNorm[0] + resultNorm[1] + resultNorm[2];
  float chR  = (rSum > 0.0f) ? resultNorm[0] / rSum : 0.0f;
  float chG  = (rSum > 0.0f) ? resultNorm[1] / rSum : 0.0f;
  float chB  = (rSum > 0.0f) ? resultNorm[2] / rSum : 0.0f;
  bool  sat  = (resultRaw[0] >= 65530 || resultRaw[1] >= 65530 ||
                resultRaw[2] >= 65530 || resultRaw[3] >= 65530);

  Serial.print(F("  raw  R=")); Serial.print(resultRaw[0]);
  Serial.print(F(" G="));       Serial.print(resultRaw[1]);
  Serial.print(F(" B="));       Serial.print(resultRaw[2]);
  Serial.print(F(" C="));       Serial.print(resultRaw[3]);
  Serial.println(sat ? F(" [SATURATED]") : F(""));

  Serial.print(F("  norm Rn=")); Serial.print(resultNorm[0], 1);
  Serial.print(F(" Gn="));       Serial.print(resultNorm[1], 1);
  Serial.print(F(" Bn="));       Serial.println(resultNorm[2], 1);

  Serial.print(F("  chroma chR=")); Serial.print(chR, 4);
  Serial.print(F(" chG="));         Serial.print(chG, 4);
  Serial.print(F(" chB="));         Serial.println(chB, 4);

  Serial.print(F("  HSL   H=")); Serial.print(resultHSL[0], 4);
  Serial.print(F(" S="));        Serial.print(resultHSL[1], 4);
  Serial.print(F(" L="));        Serial.println(resultHSL[2], 4);
}

void addColorToMedianColors(int noOfTest) {
  medianHSL[noOfTest][0] = resultHSL[0];
  medianHSL[noOfTest][1] = resultHSL[1];
  medianHSL[noOfTest][2] = resultHSL[2];
}

int getNextFreeArrayPlace() {
  int arrayCounter = 0;
  while (arrayCounter < 16 && storedColors[arrayCounter][0] >= 0.0f) {
    arrayCounter++;
  }
  return arrayCounter;
}

void clearMedianColors() {
  memset(medianHSL, 0, sizeof(medianHSL));
}

/*
 * Compute the mean of the 4 accumulated HSL samples and store.
 * Hue uses circular mean (via sin/cos) to handle the 0/1 wrap-around correctly.
 * S and L use a simple arithmetic mean.
 */
void calcMedianAndStore() {
  // Circular mean for hue (0..1 maps to 0..2π)
  float sinSum = 0.0f, cosSum = 0.0f;
  float sSum   = 0.0f, lSum   = 0.0f;
  for (int j = 0; j < 4; j++) {
    float rad = medianHSL[j][0] * 2.0f * (float)M_PI;
    sinSum += sinf(rad);
    cosSum += cosf(rad);
    sSum   += medianHSL[j][1];
    lSum   += medianHSL[j][2];
  }
  float meanRad = atan2f(sinSum, cosSum);
  if (meanRad < 0.0f) meanRad += 2.0f * (float)M_PI;
  resultHSL[0] = meanRad / (2.0f * (float)M_PI);
  resultHSL[1] = sSum / 4.0f;
  resultHSL[2] = lSum / 4.0f;

  int nextColorNo = getNextFreeArrayPlace();
  storeColor(nextColorNo, resultHSL[0], resultHSL[1], resultHSL[2]);

  Serial.print(F("Stored color to bank #")); Serial.print(nextColorNo);
  Serial.print(F("  H=")); Serial.print(resultHSL[0], 4);
  Serial.print(F("  S=")); Serial.print(resultHSL[1], 4);
  Serial.print(F("  L=")); Serial.println(resultHSL[2], 4);
}

/*
 * Default color set — placeholder only.
 * The previous values were raw RGBC sensor counts that cannot be directly
 * converted to the normalised HSL space used here.
 * Re-register each color manually via the setup-button flow.
 */
void importDefaultColorSet() {
  Serial.println(F("[WARN] Default color set unavailable: raw RGBC values have been"));
  Serial.println(F("       replaced by HSL. Re-register each color with the setup button."));
}

// Returns color name as a flash string pointer — no RAM allocation.
const __FlashStringHelper* getColorNameFromNo(int colorNo) {
  switch (colorNo) {
    case 0:  return F("Color 0");
    case 1:  return F("Color 1");
    case 2:  return F("Color 2");
    case 3:  return F("Color 3");
    case 4:  return F("Color 4");
    case 5:  return F("Color 5");
    case 6:  return F("Color 6");
    case 7:  return F("Color 7");
    case 8:  return F("Color 8");
    case 9:  return F("Color 9");
    case 10: return F("Color 10");
    case 11: return F("Color 11");
    case 12: return F("Color 12");
    default: return F("Unknown");
  }
}

void storeColor(int index, float h, float s, float l) {
  storedColors[index][0] = h;
  storedColors[index][1] = s;
  storedColors[index][2] = l;
}

/*
 * Euclidean distance in HSL space.
 * Hue difference uses the shorter arc on the circular hue axis.
 */
float colorDistanceHSL(float* c1, float* c2)
{
  float dh = fabsf(c1[0] - c2[0]);
  if (dh > 0.5f) dh = 1.0f - dh;
  float ds = c1[1] - c2[1];
  float dl = c1[2] - c2[2];
  return sqrtf(dh*dh + ds*ds + dl*dl);
}

/*
 * Returns true when the sensor reading matches the empty-tube reference,
 * indicating no bead is present.
 */
boolean nullScan() {
  float dh = fabsf(resultHSL[0] - nullScanHSL[0]);
  if (dh > 0.5f) dh = 1.0f - dh;
  return (dh                                                                     <= nullScanOffsetH) &&
         (fabsf(resultHSL[1] - nullScanHSL[1])                                   <= nullScanOffsetS) &&
         (fabsf(resultHSL[2] - nullScanHSL[2])                                   <= nullScanOffsetL) &&
         (abs((int)resultRaw[3] - (int)nullScanRAW[3])                           <= nullScanOffsetC);
}

void setNullScanValues() {
  nullScanHSL[0] = resultHSL[0];
  nullScanHSL[1] = resultHSL[1];
  nullScanHSL[2] = resultHSL[2];
  nullScanRAW[0] = resultRaw[0];
  nullScanRAW[1] = resultRaw[1];
  nullScanRAW[2] = resultRaw[2];
  nullScanRAW[3] = resultRaw[3];

  Serial.print(F("Calib results H=")); Serial.print(nullScanHSL[0], 4);
  Serial.print(F(" S="));             Serial.print(nullScanHSL[1], 4);
  Serial.print(F(" L="));             Serial.print(nullScanHSL[2], 4);
  Serial.print(F(" rawC="));          Serial.println(nullScanRAW[3]);
}

/*
 * Search storedColors for a slot whose HSL values are within the per-channel
 * thresholds of resultHSL.  Hue comparison uses circular distance.
 * Returns the matching index, or -1 if none found.
 */
int findColorInStorage()
{
  for (int i = 0; i < 16; i++) {
    if (storedColors[i][0] < 0.0f) continue;  // empty slot

    float dh = fabsf(resultHSL[0] - storedColors[i][0]);
    if (dh > 0.5f) dh = 1.0f - dh;
    if (dh > thresholdH) continue;

    if (fabsf(resultHSL[1] - storedColors[i][1]) > thresholdS) continue;

    if (fabsf(resultHSL[2] - storedColors[i][2]) > thresholdL) continue;

    return i;
  }
  return -1;
}
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

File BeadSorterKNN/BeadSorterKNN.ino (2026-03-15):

#include <Arduino.h>
#include <Servo.h>
#include <AccelStepper.h>
#include <Wire.h>
#include <Adafruit_TCS34725.h>
#include <avr/pgmspace.h>

// ─── IntelliSense stubs (never compiled by Arduino toolchain) ───
#ifdef __INTELLISENSE__
  #define F(x) x
  #define PSTR(x) x
  #define snprintf_P snprintf
  typedef char __FlashStringHelper;
#endif

// ═══════════════════════════════════════════════════════════════════
//  Pin definitions & hardware constants  (unchanged from BeadSorter)
// ═══════════════════════════════════════════════════════════════════
#define dirPin 2
#define stepPin 3
#define motorInterfaceType 1

#define stepperMaxSpeed 6000
#define stepperAccel 9000

#define stepperStepsPerRot 200
#define stepperMicroStepping 8
#define numContainerSlots 16
#define stepperMulti (stepperStepsPerRot * stepperMicroStepping / numContainerSlots)

#define motorSpeed 255
#define GSM2 5
#define in3 7
#define in4 6
#define hopperMotorReverseTime 6000

#define setupPin 11

#define photoLEDPin 9
#define photoSensorPin A0
#define photoSensorThreshold 600
#define photoSensorCalibMinDiff 100

#define servoAngleIn 36
#define servoAngleOut 62
#define servoAngleWiggle 2
#define servoPin 8

#define SENSOR_INTEGRATION_TIME TCS34725_INTEGRATIONTIME_101MS
#define SENSOR_GAIN             TCS34725_GAIN_16X

// ═══════════════════════════════════════════════════════════════════
//  KNN classifier constants  (ported from classify_bead.py)
// ═══════════════════════════════════════════════════════════════════

// Null-scan baseline (empty chamber raw readings)
#define NULL_R 498.1f
#define NULL_G 372.2f
#define NULL_B 244.2f

// Sum threshold below which the reading is treated as empty chamber
#define NULL_SUM_THRESHOLD 50.0f

// Max corrected RGB value (for scaling to 0-1)
#define RGB_MAX 7931.9f

// Normalization parameters (mean, std) for each feature
#define NORM_H_SIN_MEAN 0.470533f
#define NORM_H_SIN_STD  0.356254f
#define NORM_H_COS_MEAN 0.488719f
#define NORM_H_COS_STD  0.642882f
#define NORM_S_MEAN     0.415330f
#define NORM_S_STD      0.189916f
#define NORM_L_MEAN     0.191847f
#define NORM_L_STD      0.165316f

#define K_NEIGHBORS 3
#define NUM_REPRESENTATIVES 190
#define NUM_CLUSTERS 38

// Maximum number of bead-color clusters that get their own container
#define MAX_SORT_CLUSTERS 11

// ─── Representative points stored in PROGMEM ───
// Each row: { h_sin, h_cos, s, l }   (original / un-normalised space)
static const float repFeatures[NUM_REPRESENTATIVES][4] PROGMEM = {
  {0.981397,0.191989,0.458726,0.240332},{0.981061,0.193701,0.460193,0.275317},
  {0.966849,0.255347,0.448422,0.228985},{0.964240,0.265030,0.453953,0.257856},
  {0.964255,0.264975,0.455514,0.185427},{0.992586,0.121547,0.350025,0.327574},
  {0.939883,-0.341498,0.265038,0.354364},{0.993824,0.110967,0.343485,0.360605},
  {0.988113,-0.153728,0.352519,0.313454},{0.992391,0.123125,0.342631,0.289752},
  {0.891929,0.452175,0.231817,0.381218},{0.959937,0.280216,0.227916,0.461589},
  {0.929334,0.369241,0.230818,0.440220},{0.929025,0.370016,0.227779,0.388530},
  {0.960432,0.278516,0.241869,0.412547},{0.920954,-0.389671,0.412970,0.079211},
  {0.972815,-0.231584,0.352991,0.100706},{0.951580,-0.307401,0.393046,0.091566},
  {0.987681,0.156480,0.333548,0.020965},{0.930853,-0.365393,0.320121,0.075996},
  {0.585068,-0.810984,0.380327,0.184110},{0.547077,-0.837082,0.417597,0.143074},
  {0.544982,-0.838448,0.393963,0.157257},{0.572035,-0.820230,0.379107,0.127504},
  {0.583186,-0.812339,0.404314,0.165704},{0.894990,-0.446087,0.142407,0.000857},
  {0.894990,-0.446087,0.124142,0.000983},{0.894990,-0.446087,0.142407,0.000857},
  {0.894990,-0.446087,0.142407,0.000857},{0.894990,-0.446087,0.142407,0.000857},
  {0.922234,-0.386632,0.074308,0.000794},{0.922234,-0.386632,0.074308,0.000794},
  {0.922234,-0.386632,0.074308,0.000794},{0.922234,-0.386632,0.074308,0.000794},
  {0.922234,-0.386632,0.074308,0.000794},{0.922234,-0.386632,0.064124,0.000920},
  {0.922234,-0.386632,0.064124,0.000920},{0.922234,-0.386632,0.064124,0.000920},
  {0.922234,-0.386632,0.064124,0.000920},{0.922234,-0.386632,0.064124,0.000920},
  {0.020072,-0.999799,0.159695,0.142822},{-0.022405,-0.999749,0.217004,0.109480},
  {-0.055008,-0.998486,0.198583,0.145347},{-0.063118,-0.998006,0.255538,0.118872},
  {-0.016961,-0.999856,0.219937,0.142700},{0.547524,0.836790,0.365807,0.457188},
  {0.567393,0.823447,0.367812,0.506230},{0.563056,0.826419,0.360422,0.482906},
  {0.612779,0.790254,0.364944,0.514614},{0.534926,0.844899,0.387775,0.510516},
  {0.459499,-0.888178,0.170173,0.201445},{0.405781,-0.913970,0.210897,0.177492},
  {0.298850,-0.954300,0.201876,0.184173},{0.321960,-0.946753,0.175123,0.165515},
  {0.448152,-0.893957,0.211814,0.185056},{0.424726,-0.905322,0.293819,0.218150},
  {0.352627,-0.935764,0.325650,0.203021},{0.351339,-0.936248,0.302311,0.183039},
  {0.386276,-0.922383,0.272756,0.186695},{0.391780,-0.920059,0.315312,0.233468},
  {0.286396,0.958111,0.248089,0.233535},{0.223224,0.974767,0.293115,0.240028},
  {0.329882,0.944022,0.269887,0.286611},{0.236568,0.971615,0.281036,0.205484},
  {0.245203,0.969472,0.285723,0.260136},{0.073528,0.997293,0.302607,0.103554},
  {0.221102,0.975251,0.342138,0.115909},{0.096842,0.995300,0.264220,0.141502},
  {0.080080,0.996788,0.283038,0.090001},{0.109854,0.993948,0.301340,0.107336},
  {0.834670,0.550750,0.136718,0.001435},{0.834670,0.550750,0.136718,0.001435},
  {0.834670,0.550750,0.136718,0.001435},{0.834670,0.550750,0.136718,0.001435},
  {0.834670,0.550750,0.136718,0.001435},{0.842571,0.538585,0.173035,0.001498},
  {0.842571,0.538585,0.159606,0.001624},{0.842571,0.538585,0.173035,0.001498},
  {0.842571,0.538585,0.173035,0.001498},{0.842571,0.538585,0.173035,0.001498},
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
};

// Cluster ID for each representative point (parallel to repFeatures)
static const uint8_t repCluster[NUM_REPRESENTATIVES] PROGMEM = {
   0, 0, 0, 0, 0,  1, 1, 1, 1, 1,  2, 2, 2, 2, 2,  3, 3, 3, 3, 3,
   4, 4, 4, 4, 4,  5, 5, 5, 5, 5,  6, 6, 6, 6, 6,  7, 7, 7, 7, 7,
   8, 8, 8, 8, 8,  9, 9, 9, 9, 9, 10,10,10,10,10, 11,11,11,11,11,
  12,12,12,12,12, 13,13,13,13,13, 14,14,14,14,14, 15,15,15,15,15,
  16,16,16,16,16, 17,17,17,17,17, 18,18,18,18,18, 19,19,19,19,19,
  20,20,20,20,20, 21,21,21,21,21, 22,22,22,22,22, 23,23,23,23,23,
  24,24,24,24,24, 25,25,25,25,25, 26,26,26,26,26, 27,27,27,27,27,
  28,28,28,28,28, 29,29,29,29,29, 30,30,30,30,30, 31,31,31,31,31,
  32,32,32,32,32, 33,33,33,33,33, 34,34,34,34,34, 35,35,35,35,35,
  36,36,36,36,36, 37,37,37,37,37,
};

// ═══════════════════════════════════════════════════════════════════
//  Global objects
// ═══════════════════════════════════════════════════════════════════
Adafruit_TCS34725 tcs = Adafruit_TCS34725(SENSOR_INTEGRATION_TIME, SENSOR_GAIN);
Servo servo;
AccelStepper stepper = AccelStepper(motorInterfaceType, stepPin, dirPin);

uint16_t resultRaw[4]  = {0, 0, 0, 0};     // R, G, B, C raw sensor counts
uint16_t beadCounter = 0;
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

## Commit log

2026-03-05 Consolidating STLs adding modified code and code Documentation
    [0-Hopper_Modified_Cleaned_up.stl, 0-hopper-seq-plate-4_holes_modified.stl, 0-hopper-seq-stopper.stl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]
2026-03-09 Debugging and updating
    [2_Sequencer_tube_modified_v4_AntiStall.stl, 3-analyzer-separation-arm_modified.stl, Beadsorter.3mf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]
2026-03-09 Adjusted Servo Settings
2026-03-09 Correcting Stepper Test Code
    [BeadSorter.ino]
2026-03-09 Fixed button wiring.
2026-03-09 Enlarged some of the bead path ways. Changed container order to start the arm in the middle slot.
    [2_Sequencer_tube_modified_v2.stl, 3-analyzer-entry-tube_Extended.stl, 4-dispatcher-tube.stl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]
2026-03-10 Improving Servo Handling
2026-03-10 Updated Analyzer Structure
    [3-analyzer-exit-base_v3.stl, 3-analyzer-separation-arm_v7.stl, Beadsorter.3mf]
2026-03-10 Added Servo Calibration mode.
2026-03-10 Adjusted Angle based on new Servo
2026-03-10 Added "Wiggle In" to Servo calibration steps.
2026-03-10 Adjustments for Stuck beads
    [0_HopperStick Holder v2.stl, 0_Hopper_container_ring.stl, 2_Sequencer_base_modified.stl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]
2026-03-13 Chnaged a bunch of issues int he bead path to makes it more reliable. And changed the script to use HSL values
    [2_Sequencer_tube_modified_tighter_Higher_Motor.stl, 2_Sequencer_tube_modified_v11.stl, 3-analyzer-base_v2.stl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]
2026-03-13 Adjusted Servo angle.
2026-03-13 Adjusted Thresholds and created calibration Script
2026-03-13 Adjusted Calibration
2026-03-13 Added Documentation for Calibration and swatch generation.
2026-03-13 Adjusted the Sensor Window. Added some test blocks. Adjusted the Calibration script.
    [3-analyzer-exit-base_testBlocks.stl, 3-analyzer-exit-base_v8.stl]
2026-03-13 Added program for Simple calibration rig
2026-03-14 Adjusted Gain levels
    [3-analyzer-exit-base_testRigs_v2.stl, 3-analyzer-exit-base_v12.stl, Beadsorter.3mf]
2026-03-14 Updated the BeadSorting based on the analysis of the beads from the calibration
2026-03-14 Replace SafeSerial with Serial and tweak thresholds
    Comment out the SafeSerial macro and SafePrint wrapper and replace all SafeSerial.* calls with Serial.* in BeadSorter.ino to use the native Serial interface. Also tighten color matching H/S/L thresholds (H: 0.030 -> 0.026, S: 0.025 -> 0.023, L: 0.014 -> 0.012). Changes are limited to BeadSorter.ino and primarily affect logging and color-matching sensitivity.
    [BeadSorter.ino]
2026-03-14 Increase hopper reverse time and add debug/logging
    Double hopperMotorReverseTime from 3000ms to 6000ms to ensure a fuller reverse rotation for the hopper motor. Improve null-scan handling by replacing a simple dot with a descriptive Serial message ("No bead detected (null scan):"), printing the bead reading, and moving the sorter to position 15 when no bead is detected. Also add two new STL assets for the analyzer: 3-analyzer-entry-tube_modified_v8.stl and 3-analyzer-exit-base_v13.stl.
    [3-analyzer-entry-tube_modified_v8.stl, 3-analyzer-exit-base_v13.stl]
2026-03-14 Tighten color thresholds and add null-scan raw data
    Reduce lightness tolerance and tighten null-scan offsets to improve color discrimination (thresholdL 0.012 -> 0.010; nullScanOffsetH 0.07 -> 0.004; nullScanOffsetS 0.12 -> 0.006; nullScanOffsetL 0.12 -> 0.004). Add a clear-channel offset (nullScanOffsetC = 150) and a uint16_t nullScanRAW[4] array to store raw null-scan readings for calibration. These changes refine sensor calibration and enable storing raw sensor values for null/empty-tube reference.
    [BeadSorter.ino]
2026-03-14 Add raw C check to nullScan; fix types
    Include the raw color channel (C) in null-scan detection and correct related types/initialization. Change nullScanOffsetC from float to uint16_t, expand nullScanRAW to four uint16_t entries and initialize them to {0,0,0,0}. Update nullScan() to compare resultRaw[3] against nullScanRAW[3] (using integer abs and nullScanOffsetC). setNullScanValues() now stores resultRaw[0..3] and prints the raw C value. Also adjust Serial prints for consistency. These changes fix the previous incorrect initialization and add C-channel calibration/thresholding.
    [BeadSorter.ino]
2026-03-15 Use maxRetries; add log parser and STL
    Use the configurable maxRetries value in BeadSorter.ino (replace fixed 4 with maxRetries) to correctly aggregate retry readings.
    Add parse_sorting_log.py: a CLI tool to convert BeadSorter sorting logs to CSV (supports --containers, --no-nullscans, and --out options; summarizes per-container counts).
    Add STLs/3-analyzer-shroud.stl (3D model asset) required by the hardware/printing assets.
    [3-analyzer-shroud.stl]
2026-03-15 Add KNN classifier and remove interactive debug
    Introduce a KNN-based sorting implementation and simplify the runtime UI. Adds BeadSorterKNN.ino (KNN classifier ported from classify_bead.py with representative points in PROGMEM, cluster->container allocation, and hardware helpers). Update BeadSorter.ino: adjust H/S/L null-scan thresholds and offsets, add clear-channel tolerance (thresholdC), remove the interactive debug/calibration code and add a simple pause/resume flow on the setup button (and remove addColor flow). Also include new support files (classify_bead.py, DebugMode/DebugMode.ino) and update parse_sorting_log.py as part of this change.
    [BeadSorter.ino, BeadSorterKNN.ino, DebugMode.ino]
